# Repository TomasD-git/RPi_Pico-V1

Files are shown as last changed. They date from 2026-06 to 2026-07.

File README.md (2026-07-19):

# RPi_Pico-V1  

## Description  
**Normal RPi pico with 16Mb/128Mbit of flash (which is 8x more than clasic rpi pico)**  

- Supports any firmware compatible with rpi pico, just make sure to select 16mb flash to use full storage.    

**i made this project because RPi picos dont have usb-c port and have less storage**  

###### BOM is at the very bottom  
###### lcsc BOM is in production folder  

## Pictures  

**Schematic**  
  

**PCB**  
  

**3D viewer (Top view)**  
  

**3D viewer (Bottom view)**  


<details>
<summary>BOM</summary>

| Name | Purpose | Quantity | Total Cost (USD) | Link | Distributor |
| ---- | --- | --- | --- | ---- | --- |
| PCB + stencil | all components are on this | 1 | 34.95 | https://jlcpcb.com | jlcpcb |
|ALL components | all components that are on pcb | 1 | 35.54 | https://lcsc.com | lcsc |
| | | Total cost | 70.49 |  |  |

</details>

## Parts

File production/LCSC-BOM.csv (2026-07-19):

JLCPCB BOM Tool - BOM Matching
BOM name：bom-JLCPCB Assembly Order.xlsx |  |  | Download Time：2026-06-19 15:28:38 |  |  |  | * Our matching results are updated in real-time, but stock and prices may change. If it's been over 24 hours, please re-match before placing your order.
PCB Assembled Qty：5 |  |  | Est. Total Price：18.0146
Your BOM |  |  |  |  | Matched Parts |  |  |  |  |  |  | Order Information
Top Designator | Bottom Designator | Comment | Footprint | JLCPCB Part # | Matches | Part # | Manufacturer | Footprint | Description | Category | Warning | JLCPCB Part # | Product link | Lib Type | Qty | Source | Total Price ($)
C1,C3 |  | 47uF | 1206 |  | Select by System | CL31A476MPHNNNE | Samsung Electro-Mechanics | 1206 | 10V 47uF X5R ±20% 1206 Multilayer Ceramic Capacitors MLCC - SMD/SMT ROHS | Multilayer Ceramic Capacitors MLCC - SMD/SMT |  | C96123 | https://jlcpcb.com/partdetail/97327-CL31A476MPHNNNE/C96123 | Basic | 8 | 8 JLCPCB | 1.5152
C6 |  | 1nF | 0402 |  | Select by Customer | GCM1555C1H102FA16D | Murata Electronics | 0402 | 1nF 50V C0G ±1% 0402 Multilayer Ceramic Capacitors MLCC - SMD/SMT ROHS | Multilayer Ceramic Capacitors MLCC - SMD/SMT |  | C126493 | https://jlcpcb.com/partdetail/137773-GCM1555C1H102FA16D/C126493 | Extended | 20 | 20 JLCPCB | 0.944
C7,C8 |  | 15pF | 0402 |  | Select by Customer | GRM1555C1H150GA01D | Murata Electronics | 0402 | 15pF 50V C0G ±2% 0402 Multilayer Ceramic Capacitors MLCC - SMD/SMT ROHS | Multilayer Ceramic Capacitors MLCC - SMD/SMT |  | C161531 | https://jlcpcb.com/partdetail/172912-GRM1555C1H150GA01D/C161531 | Extended | 20 | 20 JLCPCB | 0.112
C10,C11,C12,C13,C14,C15,C16,C4,C9 | C2,C20 | 100nF | 0603 |  | Select by System | CC0603KRX7R9BB104 | YAGEO | 0603 | 100nF 50V X7R ±10% 0603 Multilayer Ceramic Capacitors MLCC - SMD/SMT ROHS | Multilayer Ceramic Capacitors MLCC - SMD/SMT |  | C14663 | https://jlcpcb.com/partdetail/YAGEO-CC0603KRX7R9BB104/C14663 | Basic | 48 | 48 JLCPCB | 0.816
C17,C18,C5 | C19 | 2.2uF | 0805 |  | Select by System | CL21A225KBQNNNE | Samsung Electro-Mechanics | 0805 | 2.2uF 50V X5R ±10% 0805 Multilayer Ceramic Capacitors MLCC - SMD/SMT ROHS | Multilayer Ceramic Capacitors MLCC - SMD/SMT |  | C377773 | https://jlcpcb.com/partdetail/350246-CL21A225KBQNNNE/C377773 | Basic | 40 | 40 JLCPCB | 1.168
D1 |  | MBR120VLSFT1G | SOD-123F_L2.8-W1.8-LS3.7-RD |  | Select by System | MBR120VLSFT1G | onsemi | SOD-123FL | -65℃~+125℃ 1 Independent 1A 20V 300mV@1A 45A 600uA@20V SOD-123FL Schottky Diodes ROHS | Schottky Diodes |  | C223608 | https://jlcpcb.com/partdetail/onsemi-MBR120VLSFT1G/C223608 | Extended | 5 | 5 JLCPCB | 0.719
L1 |  | 2.2u | 1008 |  | Select by Customer | APH252012C2R2MP01 | APV | 1008 | 1008 Power Inductors ROHS |  |  | C42455362 | https://jlcpcb.com/partdetail/APV-APH252012C2R2MP01/C42455362 | Extended | 6 | 6 JLCPCB | 0.1968
LED1 |  | XL-1608UGC-04 | LED0603-RD_GREEN |  | Select by System | XL-1608UGC-04 | XINGLIGHT | 0603 | -40℃~+85℃ 120° 20mA 3.3V 515nm~535nm 525nm 70mW 810mcd Discrete Diode Emerald Green Top-mount Water Clear 0603 LED Indication - Discrete ROHS | LED Indication - Discrete |  | C965804 | https://jlcpcb.com/partdetail/XINGLIGHT-XL_1608UGC04/C965804 | Extended | 20 | 20 JLCPCB | 0.098
Q1 |  | DMG1012T_C2830301 | SOT-523-3_L1.6-W0.8-P1.00-LS1.6-BR |  | Select by System | DMG1012T | TECH PUBLIC | SOT-523 | -55℃~+150℃ 1 N-channel 1.1V 120pF 15pF 20V 20pF 280mW 300mΩ@2.5V 800mA N-Channel SOT-523 MOSFETs ROHS | MOSFETs |  | C2830301 | https://jlcpcb.com/partdetail/TECHPUBLIC-DMG1012T/C2830301 | Extended | 6 | 6 JLCPCB | 0.225
 | R1,R2 | 5.1K | 0603 |  | Unconfirmed | 0603WAF5101T5E | UNI-ROYAL(Uniroyal Elec) | 0603 | -55℃~+155℃ 100mW 5.1kΩ 75V Thick Film Resistor ±1% ±100ppm/℃ 0603 Chip Resistor - Surface Mount ROHS | Chip Resistor - Surface Mount | 1.The comment (0603WAF5101T5E) of this part does not match the one (5.1K) provided in your BOM. Please confirm; | C23186 | https://jlcpcb.com/partdetail/23913-0603WAF5101T5E/C23186 | Basic | 20 | 20 JLCPCB | 0.036
R3 |  | 5.6K | 0603 |  | Unconfirmed | 0603WAF5601T5E | UNI-ROYAL(Uniroyal Elec) | 0603 | -55℃~+155℃ 100mW 5.6kΩ 75V Thick Film Resistor ±1% ±100ppm/℃ 0603 Chip Resistor - Surface Mount ROHS | Chip Resistor - Surface Mount | 1.The comment (0603WAF5601T5E) of this part does not match the one (5.6K) provided in your BOM. Please confirm; | C23189 | https://jlcpcb.com/partdetail/23916-0603WAF5601T5E/C23189 | Basic | 20 | 20 JLCPCB | 0.024
R4 |  | 10K | 0603 |  | Select by Customer | RT0603BRD0710KL | YAGEO | 0603 | -55℃~+155℃ 100mW 10kΩ 75V Thin Film Resistor ±0.1% ±25ppm/℃ 0603 Chip Resistor - Surface Mount ROHS | Chip Resistor - Surface Mount | 1.The comment (RT0603BRD0710KL) of this part does not match the one (10K) provided in your BOM. Please confirm; | C95204 | https://jlcpcb.com/partdetail/YAGEO-RT0603BRD0710KL/C95204 | Extended | 20 | 20 JLCPCB | 0.478
R5,R6,R9 |  | 100K | 0603 |  | Unconfirmed | 0603WAF1003T5E | UNI-ROYAL(Uniroyal Elec) | 0603 | -55℃~+155℃ 100kΩ 100mW 75V Thick Film Resistor ±1% ±100ppm/℃ 0603 Chip Resistor - Surface Mount ROHS | Chip Resistor - Surface Mount | 1.The comment (0603WAF1003T5E) of this part does not match the one (100K) provided in your BOM. Please confirm; | C25803 | https://jlcpcb.com/partdetail/26546-0603WAF1003T5E/C25803 | Basic | 20 | 20 JLCPCB | 0.032
R8 |  | 200K | 0805 |  | Unconfirmed | 0805W8F2003T5E | UNI-ROYAL(Uniroyal Elec) | 0805 | -55℃~+155℃ 125mW 150V 200kΩ Thick Film Resistor ±1% ±100ppm/℃ 0805 Chip Resistor - Surface Mount ROHS | Chip Resistor - Surface Mount | 1.The comment (0805W8F2003T5E) of this part does not match the one (200K) provided in your BOM. Please confirm; | C17539 | https://jlcpcb.com/partdetail/18227-0805W8F2003T5E/C17539 | Basic | 20 | 20 JLCPCB | 0.056
R10 |  | 470 | 0603 |  | Unconfirmed | 0603WAF4700T5E | UNI-ROYAL(Uniroyal Elec) | 0603 | -55℃~+155℃ 100mW 470Ω 75V Thick Film Resistor ±1% ±100ppm/℃ 0603 Chip Resistor - Surface Mount ROHS | Chip Resistor - Surface Mount | 1.The comment (0603WAF4700T5E) of this part does not match the one (470) provided in your BOM. Please confirm; | C23179 | https://jlcpcb.com/partdetail/23906-0603WAF4700T5E/C23179 | Basic | 20 | 20 JLCPCB | 0.032
R11,R7 |  | 1K | 0603 |  | Unconfirmed | 0603WAF1001T5E | UNI-ROYAL(Uniroyal Elec) | 0603 | -55℃~+155℃ 100mW 1kΩ 75V Thick Film Resistor ±1% ±100ppm/℃ 0603 Chip Resistor - Surface Mount ROHS | Chip Resistor - Surface Mount | 1.The comment (0603WAF1001T5E) of this part does not match the one (1K) provided in your BOM. Please confirm; | C21190 | https://jlcpcb.com/partdetail/21904-0603WAF1001T5E/C21190 | Basic | 20 | 20 JLCPCB | 0.036
R12,R13 |  | 27 | 0603 |  | Unconfirmed | 0603WAF270JT5E | UNI-ROYAL(Uniroyal Elec) | 0603 | -55℃~+155℃ 100mW 27Ω 75V Thick Film Resistor ±1% ±200ppm/℃ 0603 Chip Resistor - Surface Mount ROHS | Chip Resistor - Surface Mount | 1.The comment (0603WAF270JT5E) of this part does not match the one (27) provided in your BOM. Please confirm; | C25190 | https://jlcpcb.com/partdetail/25933-0603WAF270JT5E/C25190 | Extended | 20 | 20 JLCPCB | 0.032
 | R14 | 1 | 0402 |  | Select by Customer | FRC0402J1R0 TS | FOJAN | 0402 | -55℃~+155℃ 1Ω 50V 62.5mW Thick Film Resistor ±200ppm/℃ ±5% 0402 Chip Resistor - Surface Mount ROHS | Chip Resistor - Surface Mount | 1.The comment (FRC0402J1R0 TS) of this part does not match the one (1) provided in your BOM. Please confirm; | C2906901 | https://jlcpcb.com/partdetail/FOJAN-FRC0402J1R0TS/C2906901 | Extended | 20 | 20 JLCPCB | 0.038
 | R15 | 200 | 0603 |  | Select by Customer | 0603WAF2000T5E | UNI-ROYAL(Uniroyal Elec) | 0603 | -55℃~+155℃ 100mW 200Ω 75V Thick Film Resistor ±1% ±100ppm/℃ 0603 Chip Resistor - Surface Mount ROHS | Chip Resistor - Surface Mount | 1.The comment (0603WAF2000T5E) of this part does not match the one (200) provided in your BOM. Please confirm; | C8218 | https://jlcpcb.com/partdetail/8708-0603WAF2000T5E/C8218 | Basic | 20 | 20 JLCPCB | 0.032
SW1 |  | TS3425BA | SW-SMD_4P-L4.2-W3.2-P2.15-LS4.6-1 |  | Select by System | TS3425BA | SHOU HAN | SMD-4P,4.2x3.2mm | -20℃~+70℃ 12V 2.5N 2.5mm 3.2mm 30,000 cycles 4.2mm 50mA J-Lead No Oval Button SPST Surface Mount,Vertical White Without Bracket SMD-4P,4.2x3.2mm Tactile Switches ROHS | Tactile Switches |  | C2681476 | https://jlcpcb.com/partdetail/SHOUHAN-TS3425BA/C2681476 | Extended | 7 | 7 JLCPCB | 0.2632
U1 |  | TPS63001DRCR | VSON-10_L3.0-W3.0-P0.50-TL-EP_TPS62410DRCR |  | Select by System | TPS63001DRCR | Texas Instruments | VSON-10-EP(3x3) | -40℃~+85℃@(TA) 1 1.5MHz 1.8V~5.5V 3.3V 50uA Buck-Boost Buck-Boost Built-in Fixed Yes VSON-10-EP(3x3) DC-DC Converters ROHS | DC-DC Converters |  | C28060 | https://jlcpcb.com/partdetail/TexasInstruments-TPS63001DRCR/C28060 | Extended | 2 | 2 JLCPCB | 3.5554
U2 |  | W25Q128JVSIQTR | SOIC-8_L5.3-W5.3-P1.27-LS8.0-BL |  | Select by System | W25Q128JVSIQ | Winbond Elec | SOIC-8-208mil | -40℃~+85℃ 100,000 cycles 120ms@(32KB) 128Mbit 133MHz 1uA 2.7V~3.6V 20 Years 3ms Power-on reset、Hardware write protection、Software write protection、Write enable latch、Absolute write protection SPI SOIC-8-208mil NOR FLASH ROHS | NOR FLASH |  | C97521 | https://jlcpcb.com/partdetail/WinbondElec-W25Q128JVSIQ/C97521 | Basic | 2 | 2 JLCPCB | 4.8588
U3 |  | RP2040 | LQFN-56_L7.0-W7.0-P0.4-EP |  | Select by System | RP2040 | Raspberry Pi | LQFN-56(7x7) | 12bit 133MHz 30 LQFN-56(7x7) Microcontrollers (MCU/MPU/SOC) ROHS | Microcontrollers (MCU/MPU/SOC) |  | C2040 | https://jlcpcb.com/partdetail/RaspberryPi-RP2040/C2040 | Extended | 2 | 2 JLCPCB | 1.9714
USB1 |  | TYPE-C16PIN2MD | USB-C-SMD_TYPE-C-16PIN-2MD-073 |  | Select by System | TYPE-C 16PIN 2MD(073) | SHOU HAN | SMD | -25℃~+85℃ 1 16P 3A 5,000 times 5V Black Female Surface Mount, Right Angle Type-C SMD USB Connectors ROHS | USB Connectors |  | C2765186 | https://jlcpcb.com/partdetail/SHOUHAN-TYPE_C_16PIN_2MD_073/C2765186 | Extended | 3 | 3 JLCPCB | 0.2208
X1 |  | XL2EL89COI-111YLC-12MHz | CRYSTAL-SMD_4P-L3.2-W2.5-BL-1 |  | Select by System | XL2EL89COI-111YLC-12M | YXC Crystal Oscillators | SMD3225-4P | -40℃~+85℃ 12MHz 12pF Crystal Oscillator ±10ppm ±20ppm SMD3225-4P Crystals ROHS | Crystals |  | C5280578 | https://jlcpcb.com/partdetail/6016760-XL2EL89COI_111YLC12M/C5280578 | Extended | 6 | 6 JLCPCB | 0.555
_86,_85,_84,_83,_82,_81,_80,_79,_78,_77,_76,_75,_74,_73,_72,_71,_70,_69,_68,_67,_66,_65,_64,_63,_62,_61,_60,_59,_58,_57,_56,_55,_54,_53,_52,_51,_50,_49,_48,_47,_46,_45,_44 | _43,_42,_41,_40,_39,_38,_37,_36,_35,_34,_33,_32,_31,_30,_29,_28,_27,_26,_25,_24,_23,_22,_21,_20,_19,_18,_17,_16,_15,_14,_13,_12,_11,_10,_9,_8,_7,_6,_5,_4,_3,_2 |  |  |  | No matches | No Part Selected

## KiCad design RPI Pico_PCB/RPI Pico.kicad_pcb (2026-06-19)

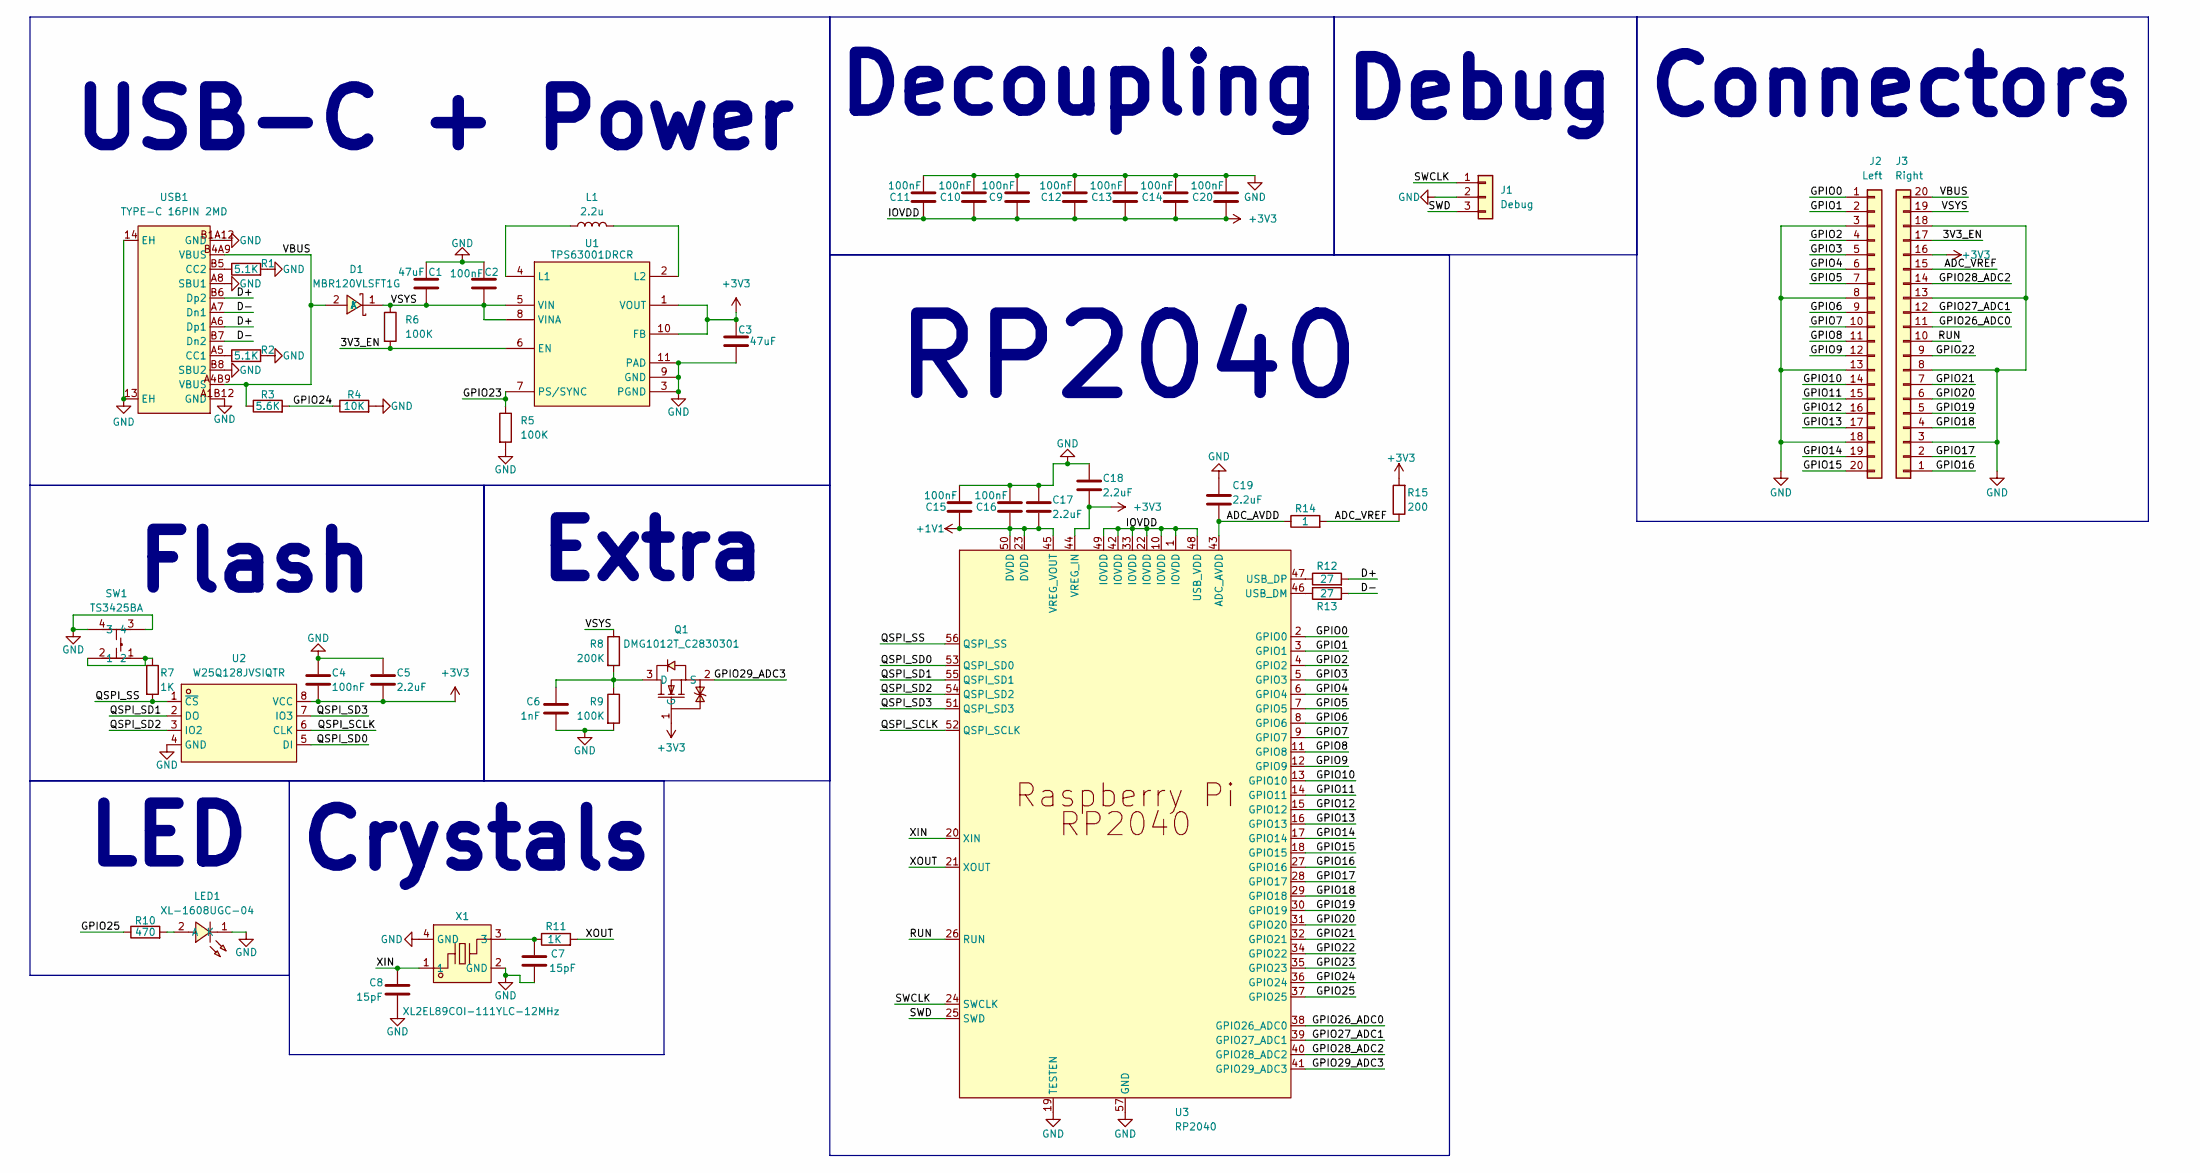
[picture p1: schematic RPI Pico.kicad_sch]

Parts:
C1, C3: 47uF; C_1206_3216Metric
C2, C4, C9, C10, C11, C12, C13, C14, C15, C16, C20: 100nF; C_0603_1608Metric
C5, C17, C18, C19: 2.2uF; C_0805_2012Metric
C6: 1nF; C_0402_1005Metric
C7, C8: 15pF; C_0402_1005Metric
D1: MBR120VLSFT1G; SOD-123F_L2.8-W1.8-LS3.7-RD; MPN MBR120VLSFT1G; LCSC Part C223608
J1: Debug
J2: Left
J3: Right
L1: 2.2u; L_1008_2520Metric
LED1: XL-1608UGC-04; LED0603-RD_GREEN; MPN XL-1608UGC-04; LCSC Part C965804
Q1: DMG1012T_C2830301; SOT-523-3_L1.6-W0.8-P1.00-LS1.6-BR; MPN DMG1012T; LCSC Part C2830301
R1, R2: 5.1K; R_0603_1608Metric
R3: 5.6K; R_0603_1608Metric
R4: 10K; R_0603_1608Metric
R5, R6, R9: 100K; R_0603_1608Metric
R7, R11: 1K; R_0603_1608Metric
R8: 200K; R_0805_2012Metric
R10: 470; R_0603_1608Metric
R12, R13: 27; R_0603_1608Metric
R14: 1; R_0402_1005Metric
R15: 200; R_0603_1608Metric
SW1: TS3425BA; SW-SMD_4P-L4.2-W3.2-P2.15-LS4.6-1; MPN TS3425BA; LCSC Part C2681476
U1: TPS63001DRCR; VSON-10_L3.0-W3.0-P0.50-TL-EP_TPS62410DRCR; MPN TPS63001DRCR; LCSC Part C28060
U2: W25Q128JVSIQTR; SOIC-8_L5.3-W5.3-P1.27-LS8.0-BL; MPN W25Q128JVSIQ; LCSC Part C97521
U3: RP2040; LQFN-56_L7.0-W7.0-P0.4-EP; MPN RP2040; LCSC Part C2040
USB1: TYPE-C 16PIN 2MD; USB-C-SMD_TYPE-C-16PIN-2MD-073; MPN TYPE-C 16PIN 2MD(073); LCSC Part C2765186
X1: XL2EL89COI-111YLC-12MHz; CRYSTAL-SMD_4P-L3.2-W2.5-BL-1; MPN XL2EL89COI-111YLC-12M; LCSC Part C5280578

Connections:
+1V1: C15.2, C16.2, C17.2, U3.23 (DVDD), U3.45 (VREG_VOUT), U3.50 (DVDD)
+3V3: C3.1, C4.2, C5.2, C9.2, C10.2, C11.2, C12.2, C13.2, C14.2, C18.2, C20.2, J3.16, Q1.1 (G), R15.2, U1.1 (VOUT), U1.10 (FB), U2.8 (VCC), U3.1 (IOVDD), U3.10 (IOVDD), U3.22 (IOVDD), U3.33 (IOVDD), U3.42 (IOVDD), U3.44 (VREG_IN), U3.48 (USB_VDD), U3.49 (IOVDD)
/3V3_EN: J3.17, R6.2, U1.6 (EN)
/ADC_AVDD: C19.2, R14.1, U3.43 (ADC_AVDD)
/ADC_VREF: J3.15, R14.2, R15.1
/D+: R12.2, USB1.A6 (Dp1), USB1.B6 (Dp2)
/D-: R13.2, USB1.A7 (Dn1), USB1.B7 (Dn2)
/GPIO0: J2.1, U3.2 (GPIO0)
/GPIO1: J2.2, U3.3 (GPIO1)
/GPIO2: J2.4, U3.4 (GPIO2)
/GPIO3: J2.5, U3.5 (GPIO3)
/GPIO4: J2.6, U3.6 (GPIO4)
/GPIO5: J2.7, U3.7 (GPIO5)
/GPIO6: J2.9, U3.8 (GPIO6)
/GPIO7: J2.10, U3.9 (GPIO7)
/GPIO8: J2.11, U3.11 (GPIO8)
/GPIO9: J2.12, U3.12 (GPIO9)
/GPIO10: J2.14, U3.13 (GPIO10)
/GPIO11: J2.15, U3.14 (GPIO11)
/GPIO12: J2.16, U3.15 (GPIO12)
/GPIO13: J2.17, U3.16 (GPIO13)
/GPIO14: J2.19, U3.17 (GPIO14)
/GPIO15: J2.20, U3.18 (GPIO15)
/GPIO16: J3.1, U3.27 (GPIO16)
/GPIO17: J3.2, U3.28 (GPIO17)
/GPIO18: J3.4, U3.29 (GPIO18)
/GPIO19: J3.5, U3.30 (GPIO19)
/GPIO20: J3.6, U3.31 (GPIO20)
/GPIO21: J3.7, U3.32 (GPIO21)
/GPIO22: J3.9, U3.34 (GPIO22)
/GPIO23: R5.1, U1.7 (PS/SYNC), U3.35 (GPIO23)
/GPIO24: R3.2, R4.1, U3.36 (GPIO24)
/GPIO25: R10.1, U3.37 (GPIO25)
/GPIO26_ADC0: J3.11, U3.38 (GPIO26_ADC0)
/GPIO27_ADC1: J3.12, U3.39 (GPIO27_ADC1)
/GPIO28_ADC2: J3.14, U3.40 (GPIO28_ADC2)
/GPIO29_ADC3: Q1.2 (S), U3.41 (GPIO29_ADC3)
/QSPI_SCLK: U2.6 (CLK), U3.52 (QSPI_SCLK)
/QSPI_SD0: U2.5 (DI), U3.53 (QSPI_SD0)
/QSPI_SD1: U2.2 (DO), U3.55 (QSPI_SD1)
/QSPI_SD2: U2.3 (IO2), U3.54 (QSPI_SD2)
/QSPI_SD3: U2.7 (IO3), U3.51 (QSPI_SD3)
/QSPI_SS: R7.2, U2.1 (~CS), U3.56 (QSPI_SS)
/RUN: J3.10, U3.26 (RUN)
/SWCLK: J1.1, U3.24 (SWCLK)
/SWD: J1.3, U3.25 (SWD)
/VBUS: D1.2 (A), J3.20, R3.1, USB1.A4B9 (VBUS), USB1.B4A9 (VBUS)
/VSYS: C1.2, C2.2, D1.1 (K), J3.19, R6.1, R8.1, U1.5 (VIN), U1.8 (VINA)
/XIN: C8.1, U3.20 (XIN), X1.1
/XOUT: R11.2, U3.21 (XOUT)
GND: C1.1, C2.1, C3.2, C4.1, C5.1, C6.1, C7.2, C8.2, C9.1, C10.1, C11.1, C12.1, C13.1, C14.1, C15.1, C16.1, C17.1, C18.1, C19.1, C20.1, J1.2, J2.3, J2.8, J2.13, J2.18, J3.3, J3.8, J3.13, J3.18, LED1.1 (K), R1.2, R2.2, R4.2, R5.2, R9.2, SW1.3, SW1.4, U1.3 (PGND), U1.9 (GND), U1.11 (PAD), U2.4 (GND), U3.19 (TESTEN), U3.57 (GND), USB1.13 (EH), USB1.14 (EH), USB1.A1B12 (GND), USB1.A8 (SBU1), USB1.B1A12 (GND), USB1.B8 (SBU2), X1.2 (GND), X1.4 (GND)
unnamed: C7.1, R11.1, X1.3
unnamed: LED1.2 (A), R10.2
unnamed: C6.2, Q1.3 (D), R8.2, R9.1
unnamed: R7.1, SW1.1, SW1.2
unnamed: L1.1, U1.4 (L1)
unnamed: L1.2, U1.2 (L2)
unnamed: R13.1, U3.46 (USB_DM)
unnamed: R12.1, U3.47 (USB_DP)
unnamed: R2.1, USB1.A5 (CC1)
unnamed: R1.1, USB1.B5 (CC2)

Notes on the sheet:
LED
USB-C + Power
Flash
RP2040
Extra
Connectors
Decoupling
Debug
Crystals

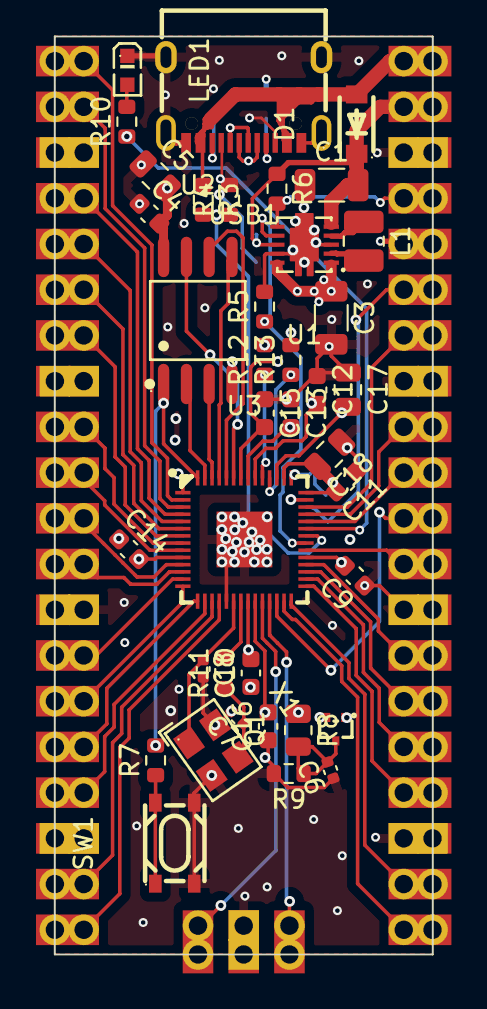
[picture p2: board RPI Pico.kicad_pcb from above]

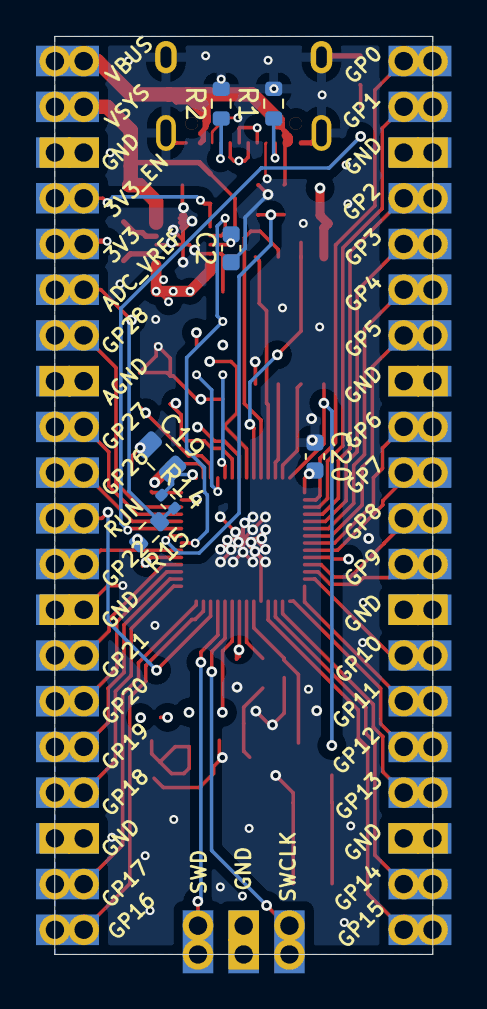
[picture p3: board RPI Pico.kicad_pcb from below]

Board: 4 copper layers, 21.0 x 51.0 mm, 45 parts (7 on the bottom side), 32 nets.

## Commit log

2026-06-19 added BOM
    [BOM.csv]
2026-06-19 added kicad files
    [RPI Pico.kicad_pcb, RPI Pico.kicad_sch, bom.csv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]
2026-06-19 added updated lcsc bom
    [RPi_Pico-LCSC BOM.xlsx]
2026-07-19 added lcsc-bom
    [LCSC-BOM.csv]
2026-07-19 Update README with BOM details
